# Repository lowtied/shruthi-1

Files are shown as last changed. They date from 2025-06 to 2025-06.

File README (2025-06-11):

Shruthi-1, a digital/analog hybrid MIDI monosynth.

This project is a redesign of the original Shruti-1, with a spec'ed up CPU,
and a focus on easy upgrades/modification of the analog section.
The ATMega644p allows new features in the firmware -- a larger selection of
oscillator algorithms, a bigger selection of wavetables, and a tiny sequencer.

Original developer: Emilie Gillet (emilie.o.gillet@gmail.com)

The firmware is released under a GPL3.0 license. It includes a
reimplementation of the formant synthesis algorithm used in Peter Knight's
Cantarino speech synthesizer.

The PCB layouts and schematics (in /hardware/shruthi/design/pcb)
are released under a Creative Commons cc-by-sa 3.0 license - except for some
discontinued filter boards which were released under a cc-by-nc-sa 3.0 license.

Documentation, analyses, simulations and 3D models are released under a
Creative Commons cc-by-sa 3.0 license.

PCB art:
- "saraswati" by Francois Barbut.
- "peacock_face" by Emilie Gillet.
- "radha" by Emilie Gillet.

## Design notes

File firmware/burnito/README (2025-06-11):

Burnito is a firmware for the Shruthi-1 digital board with a very specific
purpose: burn I2C eeproms with Shruthi-1 presets.

This firmware contains a large 16kb blob in flash with the eeprom contents. At
boot, it tries to recognize the size of the eeprom, and writes the relevant
part of this blob to the eeprom. Afterwards, the data is read back from the
eeprom and compared to the original.

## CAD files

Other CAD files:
hardware/enclosure/shruthi_xt.dwg

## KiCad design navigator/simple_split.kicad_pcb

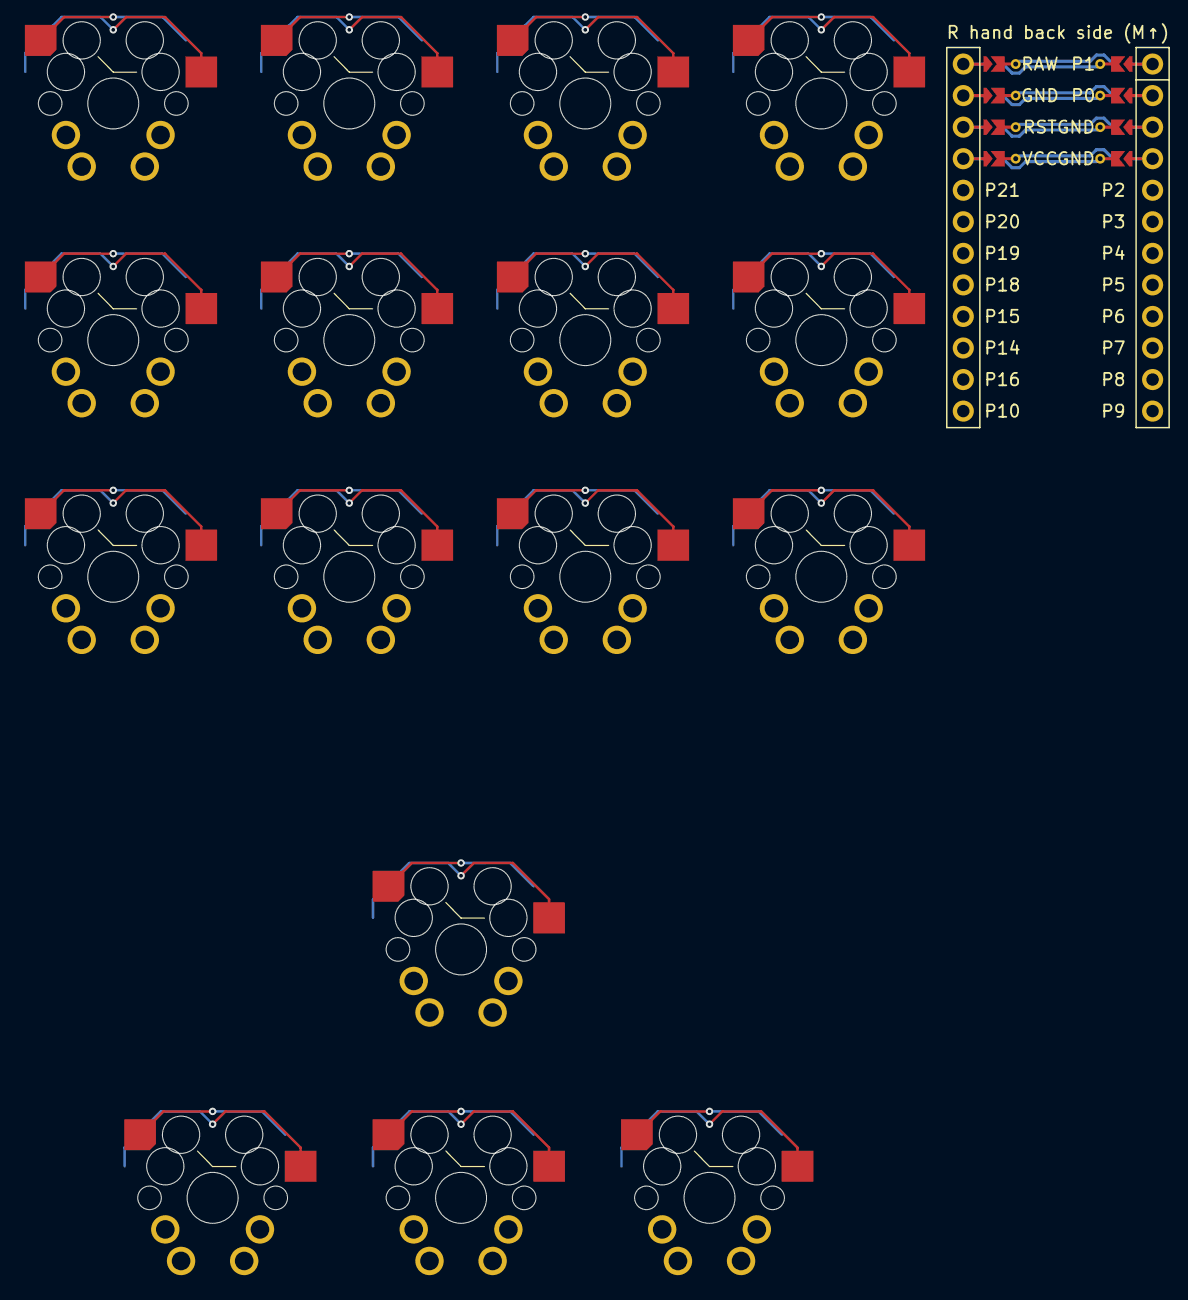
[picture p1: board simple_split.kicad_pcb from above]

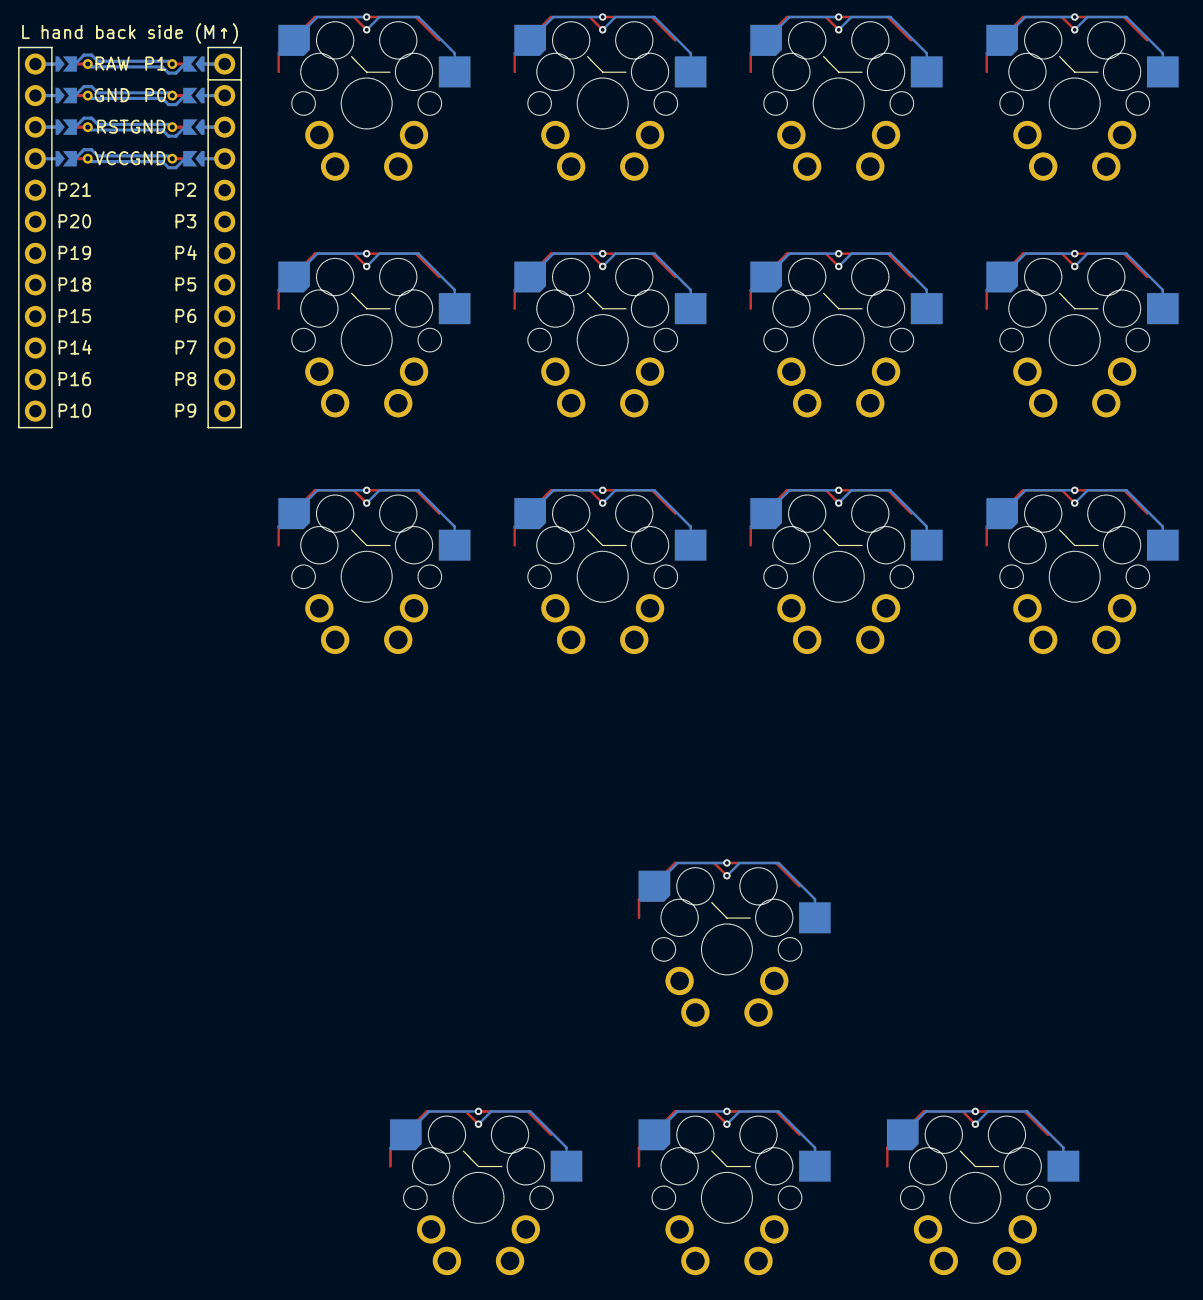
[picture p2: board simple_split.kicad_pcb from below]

Board: 2 copper layers, 17 parts (16 on the bottom side), 13 nets.

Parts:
MCU1: mcu_nice_nano
S1, S2, S3, S4, S5, S6, S7, S8, S9, S10, S11, S12, S13, S14, S15, S16: switch_mx

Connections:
GND: MCU1.103, MCU1.104, MCU1.123, S1.1, S2.1, S3.1, S4.1, S5.1, S6.1, S7.1, S8.1, S9.1, S10.1, S11.1, S12.1, S13.1, S14.1, S15.1, S16.1
matrix_inner_bottom: MCU1.9, S10.2
matrix_inner_home: MCU1.101, S11.2
matrix_inner_top: MCU1.20, S12.2
matrix_middle_bottom: MCU1.7, S7.2
matrix_middle_home: MCU1.14, S8.2
matrix_middle_top: MCU1.18, S9.2
matrix_pinky_bottom: MCU1.5, S1.2
matrix_pinky_home: MCU1.16, S2.2
matrix_pinky_top: MCU1.10, S3.2
matrix_ring_bottom: MCU1.6, S4.2
matrix_ring_home: MCU1.15, S5.2
matrix_ring_top: MCU1.17, S6.2

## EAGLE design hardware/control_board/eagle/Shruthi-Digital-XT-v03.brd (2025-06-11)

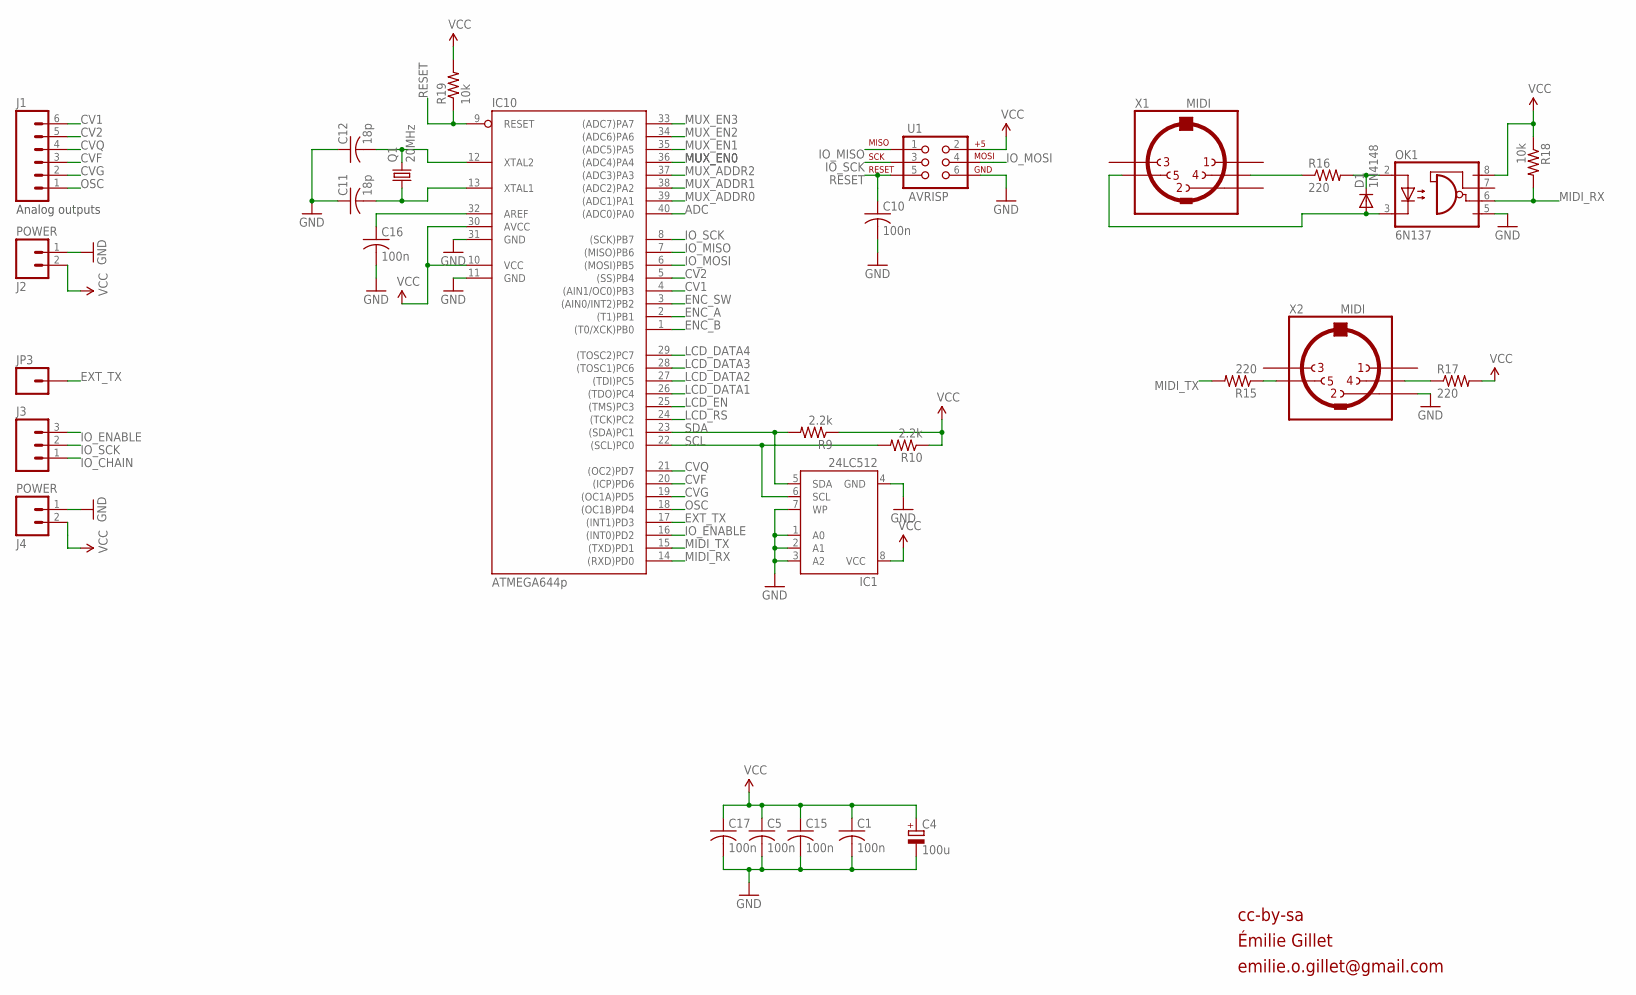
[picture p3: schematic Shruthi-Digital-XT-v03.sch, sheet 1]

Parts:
C1, C5, C10, C15, C16, C17: 100n; C025-024X044
C4: 100u; E2,5-7
C11, C12: 18p; C025-024X044
D1: 1N4148; D-5
IC1: 24LC512; DIL08
IC10: ATMEGA644p; DIL40
J1: M06SIP; 1X06
J2, J4: POWER; 1X02
J3: M03PTH; 1X03
JP3: M01PTH; 1X01
OK1: 6N137; DIL08
Q1: 20MHz; HC49U-V
R9, R10: 2.2k; 0204/7
R15, R16, R17: 220; 0204/7
R18, R19: 10k; 0204/7
U1: AVRISP; 2X3
X1, X2: MIDI; MAB5SH

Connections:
ADC: IC10.40 ((ADC0)PA0); also elsewhere on the board
CV1: IC10.4 ((AIN1/OC0)PB3), J1.6
CV2: IC10.5 ((SS)PB4), J1.5
CVF: IC10.20 ((ICP)PD6), J1.3
CVG: IC10.19 ((OC1A)PD5), J1.2
CVQ: IC10.21 ((OC2)PD7), J1.4
ENC_A: IC10.2 ((T1)PB1); also elsewhere on the board
ENC_B: IC10.1 ((T0/XCK)PB0); also elsewhere on the board
ENC_SW: IC10.3 ((AIN0/INT2)PB2); also elsewhere on the board
EXT_TX: IC10.17 ((INT1)PD3), JP3.1
GND: C1.2, C4.-, C5.2, C10.2, C11.1, C12.1, C15.2, C16.2, C17.2, IC1.1 (A0), IC1.2 (A1), IC1.3 (A2), IC1.4 (GND), IC1.7 (WP), IC10.11 (GND), IC10.31 (GND), J2.1, J4.1, OK1.5 (GND), U1.6, X2.2; also elsewhere on the board
IO_CHAIN: J3.1; also elsewhere on the board
IO_ENABLE: IC10.16 ((INT0)PD2), J3.3; also elsewhere on the board
IO_MISO: IC10.7 ((MISO)PB6), U1.1; also elsewhere on the board
IO_MOSI: IC10.6 ((MOSI)PB5), U1.4; also elsewhere on the board
IO_SCK: IC10.8 ((SCK)PB7), J3.2, U1.3; also elsewhere on the board
LCD_DATA1: IC10.26 ((TDO)PC4); also elsewhere on the board
LCD_DATA2: IC10.27 ((TDI)PC5); also elsewhere on the board
LCD_DATA3: IC10.28 ((TOSC1)PC6); also elsewhere on the board
LCD_DATA4: IC10.29 ((TOSC2)PC7); also elsewhere on the board
LCD_EN: IC10.25 ((TMS)PC3); also elsewhere on the board
LCD_RS: IC10.24 ((TCK)PC2); also elsewhere on the board
MIDI_RX: IC10.14 ((RXD)PD0), OK1.6 (VO), R18.2
MIDI_TX: IC10.15 ((TXD)PD1), R15.2
MUX_ADDR0: IC10.39 ((ADC1)PA1); also elsewhere on the board
MUX_ADDR1: IC10.38 ((ADC2)PA2); also elsewhere on the board
MUX_ADDR2: IC10.37 ((ADC3)PA3); also elsewhere on the board
MUX_EN0: IC10.36 ((ADC4)PA4); also elsewhere on the board
MUX_EN1: IC10.35 ((ADC5)PA5); also elsewhere on the board
MUX_EN2: IC10.34 ((ADC6)PA6); also elsewhere on the board
MUX_EN3: IC10.33 ((ADC7)PA7); also elsewhere on the board
unnamed: R15.1, X2.5
unnamed: C16.1, IC10.32 (AREF)
unnamed: D1.C, OK1.2 (A), R16.2
unnamed: R17.1, X2.4
unnamed: R16.1, X1.4
unnamed: D1.A, OK1.3 (C), X1.5
unnamed: C11.2, IC10.13 (XTAL1), Q1.1
unnamed: C12.2, IC10.12 (XTAL2), Q1.2
OSC: IC10.18 ((OC1B)PD4), J1.1
RESET: C10.1, IC10.9 (RESET), R19.1, U1.5
SCL: IC1.6 (SCL), IC10.22 ((SCL)PC0), R10.2
SDA: IC1.5 (SDA), IC10.23 ((SDA)PC1), R9.2
VCC: C1.1, C4.+, C5.1, C15.1, C17.1, IC1.8 (VCC), IC10.10 (VCC), IC10.30 (AVCC), J2.2, J4.2, OK1.8 (VCC), R9.1, R10.1, R17.2, R18.1, R19.2, U1.2; also elsewhere on the board

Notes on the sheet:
Analog outputs
cc-by-sa
Émilie Gillet
emilie.o.gillet@gmail.com

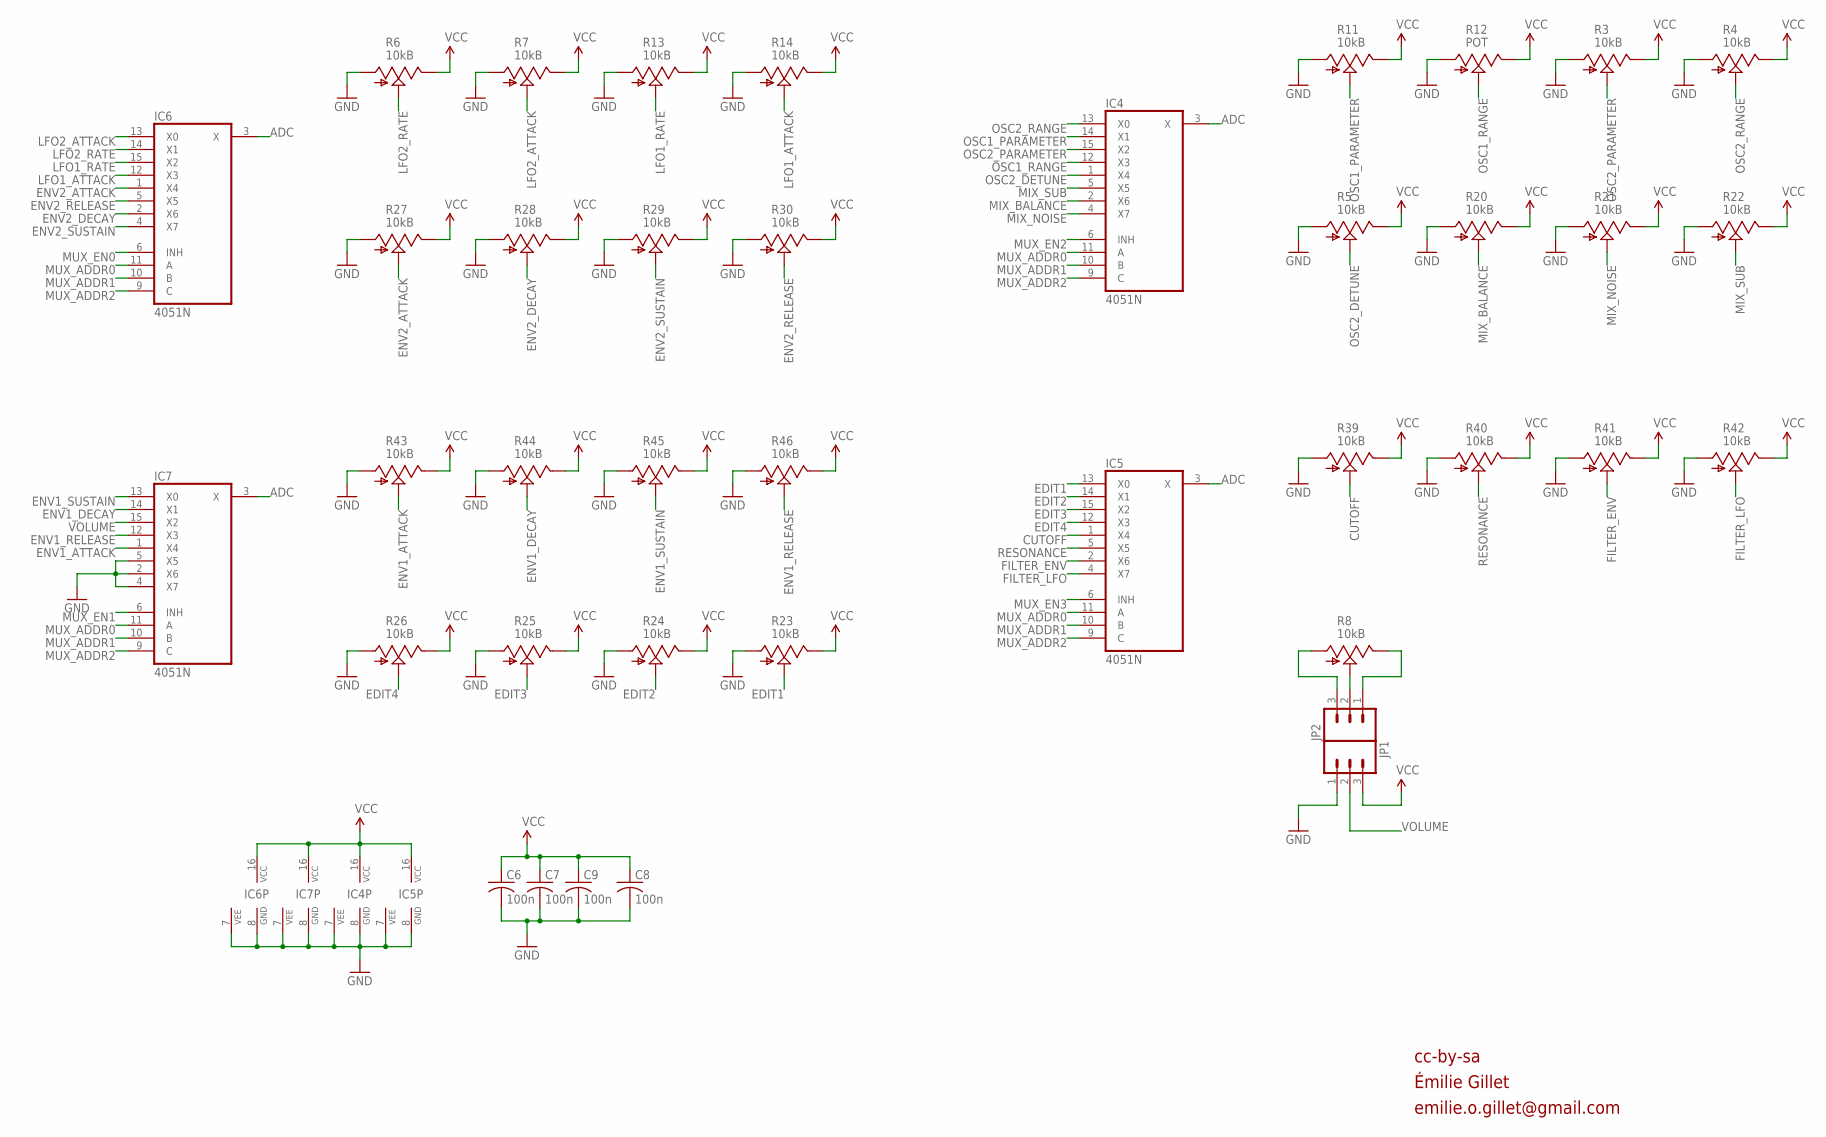
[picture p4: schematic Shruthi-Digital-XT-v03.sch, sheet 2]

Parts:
C6, C7, C8, C9: 100n; C025-024X044
IC4, IC5, IC6, IC7: 4051N; DIL16
JP1, JP2: M03PTH; 1X03
R3, R4, R5, R6, R7, R8, R11, R13, R14, R20, R21, R22, R23, R24, R25, R26, R27, R28, R29, R30, R39, R40, R41, R42, R43, R44, R45, R46: 10kB; ALPS_POT_VERTICAL
R12: POT; ALPS_POT_VERTICAL

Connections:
ADC: IC4.3 (X), IC5.3 (X), IC6.3 (X), IC7.3 (X); also elsewhere on the board
CUTOFF: IC5.1 (X4), R39.P$2 (S)
EDIT1: IC5.13 (X0), R23.P$2 (S)
EDIT2: IC5.14 (X1), R24.P$2 (S)
EDIT3: IC5.15 (X2), R25.P$2 (S)
EDIT4: IC5.12 (X3), R26.P$2 (S)
ENV1_ATTACK: IC7.1 (X4), R43.P$2 (S)
ENV1_DECAY: IC7.14 (X1), R44.P$2 (S)
ENV1_RELEASE: IC7.12 (X3), R46.P$2 (S)
ENV1_SUSTAIN: IC7.13 (X0), R45.P$2 (S)
ENV2_ATTACK: IC6.1 (X4), R27.P$2 (S)
ENV2_DECAY: IC6.2 (X6), R28.P$2 (S)
ENV2_RELEASE: IC6.5 (X5), R30.P$2 (S)
ENV2_SUSTAIN: IC6.4 (X7), R29.P$2 (S)
FILTER_ENV: IC5.2 (X6), R41.P$2 (S)
FILTER_LFO: IC5.4 (X7), R42.P$2 (S)
GND: C6.2, C7.2, C8.2, C9.2, IC4.7 (VEE), IC4.8 (GND), IC5.7 (VEE), IC5.8 (GND), IC6.7 (VEE), IC6.8 (GND), IC7.2 (X6), IC7.4 (X7), IC7.5 (X5), IC7.7 (VEE), IC7.8 (GND), JP1.1, R3.P$3 (A), R4.P$3 (A), R5.P$3 (A), R6.P$3 (A), R7.P$3 (A), R11.P$3 (A), R12.P$3 (A), R13.P$3 (A), R14.P$3 (A), R20.P$3 (A), R21.P$3 (A), R22.P$3 (A), R23.P$3 (A), R24.P$3 (A), R25.P$3 (A), R26.P$3 (A), R27.P$3 (A), R28.P$3 (A), R29.P$3 (A), R30.P$3 (A), R39.P$3 (A), R40.P$3 (A), R41.P$3 (A), R42.P$3 (A), R43.P$3 (A), R44.P$3 (A), R45.P$3 (A), R46.P$3 (A); also elsewhere on the board
LFO1_ATTACK: IC6.12 (X3), R14.P$2 (S)
LFO1_RATE: IC6.15 (X2), R13.P$2 (S)
LFO2_ATTACK: IC6.13 (X0), R7.P$2 (S)
LFO2_RATE: IC6.14 (X1), R6.P$2 (S)
MIX_BALANCE: IC4.2 (X6), R20.P$2 (S)
MIX_NOISE: IC4.4 (X7), R21.P$2 (S)
MIX_SUB: IC4.5 (X5), R22.P$2 (S)
MUX_ADDR0: IC4.11 (A), IC5.11 (A), IC6.11 (A), IC7.11 (A); also elsewhere on the board
MUX_ADDR1: IC4.10 (B), IC5.10 (B), IC6.10 (B), IC7.10 (B); also elsewhere on the board
MUX_ADDR2: IC4.9 (C), IC5.9 (C), IC6.9 (C), IC7.9 (C); also elsewhere on the board
MUX_EN0: IC6.6 (INH); also elsewhere on the board
MUX_EN1: IC7.6 (INH); also elsewhere on the board
MUX_EN2: IC4.6 (INH); also elsewhere on the board
MUX_EN3: IC5.6 (INH); also elsewhere on the board
unnamed: JP2.3, R8.P$3 (A)
unnamed: JP2.1, R8.P$1 (E)
unnamed: JP2.2, R8.P$2 (S)
OSC1_PARAMETER: IC4.14 (X1), R11.P$2 (S)
OSC1_RANGE: IC4.12 (X3), R12.P$2 (S)
OSC2_DETUNE: IC4.1 (X4), R5.P$2 (S)
OSC2_PARAMETER: IC4.15 (X2), R3.P$2 (S)
OSC2_RANGE: IC4.13 (X0), R4.P$2 (S)
RESONANCE: IC5.5 (X5), R40.P$2 (S)
VCC: C6.1, C7.1, C8.1, C9.1, IC4.16 (VCC), IC5.16 (VCC), IC6.16 (VCC), IC7.16 (VCC), JP1.3, R3.P$1 (E), R4.P$1 (E), R5.P$1 (E), R6.P$1 (E), R7.P$1 (E), R11.P$1 (E), R12.P$1 (E), R13.P$1 (E), R14.P$1 (E), R20.P$1 (E), R21.P$1 (E), R22.P$1 (E), R23.P$1 (E), R24.P$1 (E), R25.P$1 (E), R26.P$1 (E), R27.P$1 (E), R28.P$1 (E), R29.P$1 (E), R30.P$1 (E), R39.P$1 (E), R40.P$1 (E), R41.P$1 (E), R42.P$1 (E), R43.P$1 (E), R44.P$1 (E), R45.P$1 (E), R46.P$1 (E); also elsewhere on the board
VOLUME: IC7.15 (X2), JP1.2

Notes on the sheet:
cc-by-sa
Émilie Gillet
emilie.o.gillet@gmail.com

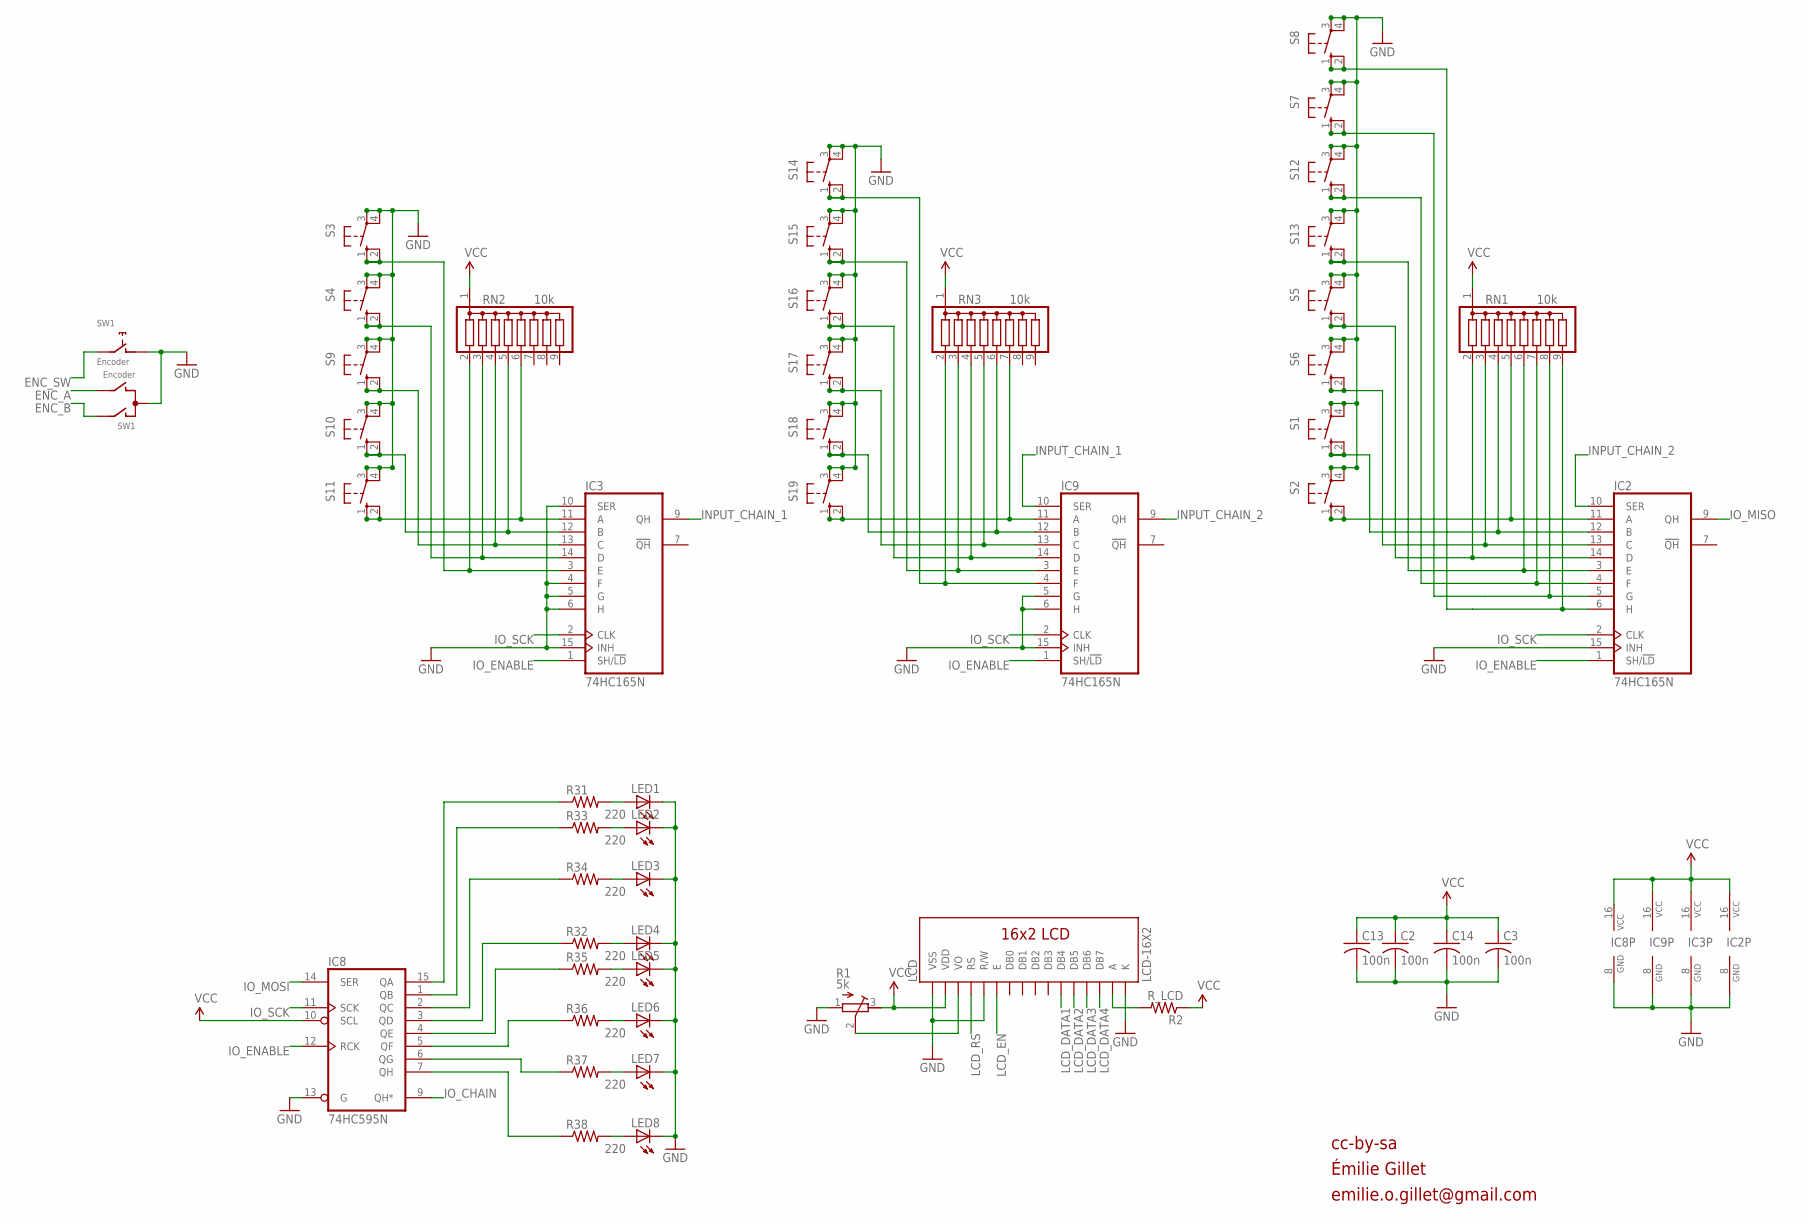
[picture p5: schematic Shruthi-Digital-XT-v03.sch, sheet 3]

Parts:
C2, C3, C13, C14: 100n; C025-024X044
IC2, IC3, IC9: 74HC165N; DIL16
IC8: 74HC595N; DIL16
LCD: LCD-16X2
LED1, LED2, LED3, LED4, LED5, LED6, LED7, LED8: LED3MM
R1: 5k; RTRIM3339P
R2: R_LCD; 0204/7
R31, R32, R33, R34, R35, R36, R37, R38: 220; 0204/7
RN1, RN2, RN3: 10k; SIL9
S1, S2, S3, S4, S5, S6, S7, S8, S9, S10, S11, S12, S13, S14, S15, S16, S17, S18, S19: 40-XX; B3F-40XX
SW1: Encoder; ALPS_EC12E_SW

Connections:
ENC_A: SW1.B; also elsewhere on the board
ENC_B: SW1.A; also elsewhere on the board
ENC_SW: SW1.E (2); also elsewhere on the board
GND: C2.2, C3.2, C13.2, C14.2, IC2.8 (GND), IC2.15 (INH), IC3.4 (F), IC3.5 (G), IC3.6 (H), IC3.8 (GND), IC3.10 (SER), IC3.15 (INH), IC8.8 (GND), IC8.13 (G), IC9.5 (G), IC9.6 (H), IC9.8 (GND), IC9.15 (INH), LCD.1 (VSS), LCD.5 (R/W), LCD.16 (K), LED1.K (C), LED2.K (C), LED3.K (C), LED4.K (C), LED5.K (C), LED6.K (C), LED7.K (C), LED8.K (C), R1.1 (E), S1.3, S1.4 (P1), S2.3, S2.4 (P1), S3.3, S3.4 (P1), S4.3, S4.4 (P1), S5.3, S5.4 (P1), S6.3, S6.4 (P1), S7.3, S7.4 (P1), S8.3, S8.4 (P1), S9.3, S9.4 (P1), S10.3, S10.4 (P1), S11.3, S11.4 (P1), S12.3, S12.4 (P1), S13.3, S13.4 (P1), S14.3, S14.4 (P1), S15.3, S15.4 (P1), S16.3, S16.4 (P1), S17.3, S17.4 (P1), S18.3, S18.4 (P1), S19.3, S19.4 (P1), SW1.C, SW1.D (1); also elsewhere on the board
INPUT_CHAIN_1: IC3.9 (QH), IC9.10 (SER)
INPUT_CHAIN_2: IC2.10 (SER), IC9.9 (QH)
IO_CHAIN: IC8.9 (QH*); also elsewhere on the board
IO_ENABLE: IC2.1 (SH/!LD), IC3.1 (SH/!LD), IC8.12 (RCK), IC9.1 (SH/!LD); also elsewhere on the board
IO_MISO: IC2.9 (QH); also elsewhere on the board
IO_MOSI: IC8.14 (SER); also elsewhere on the board
IO_SCK: IC2.2 (CLK), IC3.2 (CLK), IC8.11 (SCK), IC9.2 (CLK); also elsewhere on the board
LCD_DATA1: LCD.11 (DB4); also elsewhere on the board
LCD_DATA2: LCD.12 (DB5); also elsewhere on the board
LCD_DATA3: LCD.13 (DB6); also elsewhere on the board
LCD_DATA4: LCD.14 (DB7); also elsewhere on the board
LCD_EN: LCD.6 (E); also elsewhere on the board
LCD_RS: LCD.4 (RS); also elsewhere on the board
unnamed: IC8.2 (QC), R34.1
unnamed: IC9.11 (A), RN3.7, S19.1 (S), S19.2 (S1)
unnamed: IC9.3 (E), RN3.3, S15.1 (S), S15.2 (S1)
unnamed: IC2.4 (F), RN1.7, S12.1 (S), S12.2 (S1)
unnamed: IC2.14 (D), RN1.2, S5.1 (S), S5.2 (S1)
unnamed: IC2.13 (C), RN1.3, S6.1 (S), S6.2 (S1)
unnamed: IC2.12 (B), RN1.4, S1.1 (S), S1.2 (S1)
unnamed: IC2.11 (A), RN1.5, S2.1 (S), S2.2 (S1)
unnamed: IC2.3 (E), RN1.6, S13.1 (S), S13.2 (S1)
unnamed: IC2.5 (G), RN1.8, S7.1 (S), S7.2 (S1)
unnamed: IC2.6 (H), RN1.9, S8.1 (S), S8.2 (S1)
unnamed: IC8.15 (QA), R31.1
unnamed: IC8.1 (QB), R33.1
unnamed: IC8.3 (QD), R32.1
unnamed: IC8.4 (QE), R35.1
unnamed: IC8.5 (QF), R36.1
unnamed: IC8.7 (QH), R38.1
unnamed: IC8.6 (QG), R37.1
unnamed: IC3.14 (D), RN2.3, S4.1 (S), S4.2 (S1)
unnamed: IC3.13 (C), RN2.4, S9.1 (S), S9.2 (S1)
unnamed: IC3.12 (B), RN2.5, S10.1 (S), S10.2 (S1)
unnamed: IC3.11 (A), RN2.6, S11.1 (S), S11.2 (S1)
unnamed: LED1.A, R31.2
unnamed: LED2.A, R33.2
unnamed: LED3.A, R34.2
unnamed: LED4.A, R32.2
unnamed: LED5.A, R35.2
unnamed: LED6.A, R36.2
unnamed: LED7.A, R37.2
unnamed: LED8.A, R38.2
unnamed: IC3.3 (E), RN2.2, S3.1 (S), S3.2 (S1)
unnamed: IC9.4 (F), RN3.2, S14.1 (S), S14.2 (S1)
unnamed: IC9.14 (D), RN3.4, S16.1 (S), S16.2 (S1)
unnamed: IC9.13 (C), RN3.5, S17.1 (S), S17.2 (S1)
unnamed: IC9.12 (B), RN3.6, S18.1 (S), S18.2 (S1)
unnamed: LCD.3 (VO), R1.2 (S)
unnamed: LCD.15 (A), R2.2
VCC: C2.1, C3.1, C13.1, C14.1, IC2.16 (VCC), IC3.16 (VCC), IC8.10 (SCL), IC8.16 (VCC), IC9.16 (VCC), LCD.2 (VDD), R1.3 (A), R2.1, RN1.1, RN2.1, RN3.1; also elsewhere on the board

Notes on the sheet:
cc-by-sa
Émilie Gillet
emilie.o.gillet@gmail.com

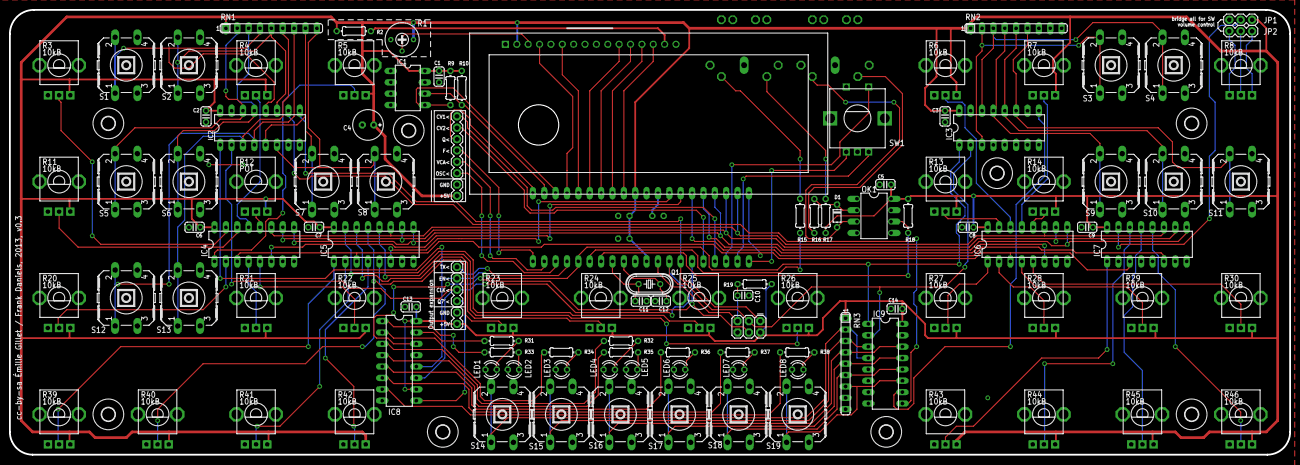
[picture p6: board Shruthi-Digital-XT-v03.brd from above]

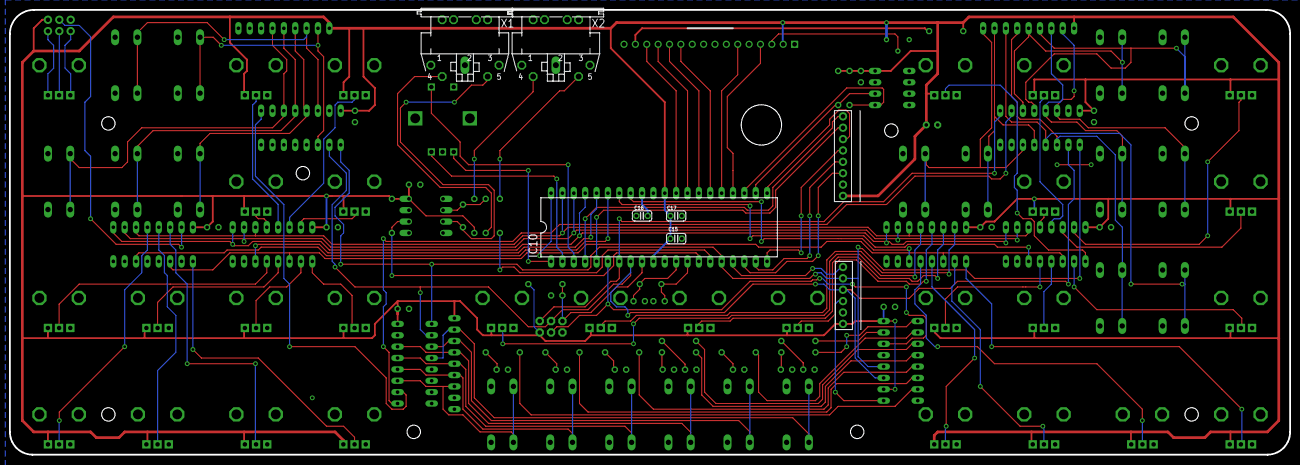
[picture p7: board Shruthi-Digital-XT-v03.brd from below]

Board: 2 copper layers, 286.0 x 99.4 mm, 128 parts (6 on the bottom side), 115 nets.

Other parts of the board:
U$1, U$3, U$4, U$6, U$7, U$8, U$10, U$11: 3,0
U$5: V2_LOGO_SHRUTHI_DIGITAL
U$9: V2_LOGO_DINGBAT1

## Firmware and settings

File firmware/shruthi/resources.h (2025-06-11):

// Copyright 2009 Emilie Gillet.
//
// Author: Emilie Gillet (emilie.o.gillet@gmail.com)
//
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
// -----------------------------------------------------------------------------
//
// Resources definitions.
//
// Automatically generated with:
// make resources


#ifndef SHRUTHI_RESOURCES_H_
#define SHRUTHI_RESOURCES_H_


#include "avrlib/base.h"

#include <avr/pgmspace.h>


#include "avrlib/resources_manager.h"

namespace shruthi {

typedef uint16_t ResourceId;

extern const prog_char* const string_table[];

extern const prog_uint16_t* const lookup_table_table[];

extern const prog_uint32_t* const lookup_table32_table[];

extern const prog_uint8_t* const waveform_table[];

extern const prog_uint8_t* const character_table[];

extern const prog_uint16_t lut_res_lfo_increments[] PROGMEM;
extern const prog_uint16_t lut_res_env_portamento_increments[] PROGMEM;
extern const prog_uint16_t lut_res_oscillator_increments[] PROGMEM;
extern const prog_uint16_t lut_res_fm_frequency_ratios[] PROGMEM;
extern const prog_uint16_t lut_res_scale_just[] PROGMEM;
extern const prog_uint16_t lut_res_scale_pythagorean[] PROGMEM;
extern const prog_uint16_t lut_res_scale_1_4_eb[] PROGMEM;
extern const prog_uint16_t lut_res_scale_1_4_e[] PROGMEM;
extern const prog_uint16_t lut_res_scale_1_4_ea[] PROGMEM;
extern const prog_uint16_t lut_res_scale_bhairav[] PROGMEM;
extern const prog_uint16_t lut_res_scale_gunakri[] PROGMEM;
extern const prog_uint16_t lut_res_scale_marwa[] PROGMEM;
extern const prog_uint16_t lut_res_scale_shree[] PROGMEM;
extern const prog_uint16_t lut_res_scale_purvi[] PROGMEM;
extern const prog_uint16_t lut_res_scale_bilawal[] PROGMEM;
extern const prog_uint16_t lut_res_scale_yaman[] PROGMEM;
extern const prog_uint16_t lut_res_scale_kafi[] PROGMEM;
extern const prog_uint16_t lut_res_scale_bhimpalasree[] PROGMEM;
extern const prog_uint16_t lut_res_scale_darbari[] PROGMEM;
extern const prog_uint16_t lut_res_scale_rageshree[] PROGMEM;
extern const prog_uint16_t lut_res_scale_khamaj[] PROGMEM;
extern const prog_uint16_t lut_res_scale_mimal[] PROGMEM;
extern const prog_uint16_t lut_res_scale_parameshwari[] PROGMEM;
extern const prog_uint16_t lut_res_scale_rangeshwari[] PROGMEM;
extern const prog_uint16_t lut_res_scale_gangeshwari[] PROGMEM;
extern const prog_uint16_t lut_res_scale_kameshwari[] PROGMEM;
extern const prog_uint16_t lut_res_scale_palas_kafi[] PROGMEM;
extern const prog_uint16_t lut_res_scale_natbhairav[] PROGMEM;
extern const prog_uint16_t lut_res_scale_m_kauns[] PROGMEM;
extern const prog_uint16_t lut_res_scale_bairagi[] PROGMEM;
extern const prog_uint16_t lut_res_scale_b_todi[] PROGMEM;
extern const prog_uint16_t lut_res_scale_chandradeep[] PROGMEM;
extern const prog_uint16_t lut_res_scale_kaushik_todi[] PROGMEM;
extern const prog_uint16_t lut_res_scale_jogeshwari[] PROGMEM;
extern const prog_uint16_t lut_res_arpeggiator_patterns[] PROGMEM;
extern const prog_uint16_t lut_res_groove_swing[] PROGMEM;
extern const prog_uint16_t lut_res_groove_shuffle[] PROGMEM;
extern const prog_uint16_t lut_res_groove_push[] PROGMEM;
extern const prog_uint16_t lut_res_groove_lag[] PROGMEM;
extern const prog_uint16_t lut_res_groove_human[] PROGMEM;
extern const prog_uint16_t lut_res_groove_monkey[] PROGMEM;
extern const prog_uint32_t lut_res_tempo_phase_increment[] PROGMEM;
extern const prog_uint8_t wav_res_formant_sine[] PROGMEM;
extern const prog_uint8_t wav_res_formant_square[] PROGMEM;
extern const prog_uint8_t wav_res_sine[] PROGMEM;
extern const prog_uint8_t wav_res_bandlimited_square_0[] PROGMEM;
extern const prog_uint8_t wav_res_bandlimited_square_1[] PROGMEM;
extern const prog_uint8_t wav_res_bandlimited_square_2[] PROGMEM;
extern const prog_uint8_t wav_res_bandlimited_square_3[] PROGMEM;
extern const prog_uint8_t wav_res_bandlimited_square_4[] PROGMEM;
extern const prog_uint8_t wav_res_bandlimited_square_5[] PROGMEM;
extern const prog_uint8_t wav_res_bandlimited_saw_0[] PROGMEM;
extern const prog_uint8_t wav_res_bandlimited_saw_1[] PROGMEM;
extern const prog_uint8_t wav_res_bandlimited_saw_2[] PROGMEM;
extern const prog_uint8_t wav_res_bandlimited_saw_3[] PROGMEM;
extern const prog_uint8_t wav_res_bandlimited_saw_4[] PROGMEM;
extern const prog_uint8_t wav_res_bandlimited_saw_5[] PROGMEM;
extern const prog_uint8_t wav_res_bandlimited_triangle_0[] PROGMEM;
extern const prog_uint8_t wav_res_bandlimited_triangle_3[] PROGMEM;
extern const prog_uint8_t wav_res_bandlimited_triangle_4[] PROGMEM;
extern const prog_uint8_t wav_res_bandlimited_triangle_5[] PROGMEM;
extern const prog_uint8_t wav_res_vowel_data[] PROGMEM;
extern const prog_uint8_t wav_res_distortion[] PROGMEM;
extern const prog_uint8_t wav_res_env_expo[] PROGMEM;
extern const prog_uint8_t wav_res_ssm2164_linearization[] PROGMEM;
extern const prog_uint8_t wav_res_waves[] PROGMEM;
extern const prog_uint8_t wav_res_wavetables[] PROGMEM;
extern const prog_uint8_t wav_res_version[] PROGMEM;
extern const prog_uint8_t chr_res_special_characters[] PROGMEM;
#define STR_RES_SHAPE 0  // shape
#define STR_RES_PARAMETER 1  // parameter
#define STR_RES_RESONANCE 2  // resonance
#define STR_RES_PRM 3  // prm
#define STR_RES_RANGE 4  // range
#define STR_RES_RNG 5  // rng
#define STR_RES_OP_ 6  // op.
#define STR_RES_OPERATOR 7  // operator
#define STR_RES_DETUNE 8  // detune
#define STR_RES_OSC_MIX 9  // osc mix
#define STR_RES_SUB_OSC_ 10  // sub osc.
#define STR_RES_ENV1TVCF 11  // env1~vcf
#define STR_RES_LFO2TVCF 12  // lfo2~vcf
#define STR_RES_ATTACK 13  // attack
#define STR_RES_ATK 14  // atk
#define STR_RES_DECAY 15  // decay
#define STR_RES_SUSTAIN 16  // sustain
#define STR_RES_RELEASE 17  // release
#define STR_RES_RATE 18  // rate
#define STR_RES_MODULATION 19  // modulation
#define STR_RES_OPERATORS 20  // operators
#define STR_RES_MOD_ 21  // mod.
#define STR_RES_SOURCE 22  // source
#define STR_RES_SRC 23  // src
#define STR_RES_DEST_ 24  // dest.
#define STR_RES_DST 25  // dst
#define STR_RES_AMOUNT 26  // amount
#define STR_RES_AMT 27  // amt
#define STR_RES_MODE 28  // mode
#define STR_RES_OVERDRIVE 29  // overdrive
#define STR_RES__FM 30  // fm
#define STR_RES_FLAVOUR 31  // flavour
#define STR_RES_TIME 32  // time
#define STR_RES_LEVEL 33  // level
#define STR_RES_FDB 34  // fdb
#define STR_RES_FEEDBACK 35  // feedback
#define STR_RES_EQ_ 36  // eq.
#define STR_RES_FDBCK_EQ_ 37  // fdbck eq.
#define STR_RES_TEMPO 38  // tempo
#define STR_RES_BPM 39  // bpm
#define STR_RES_GROOVE 40  // groove
#define STR_RES_DIRECTION 41  // direction
#define STR_RES_PATTERN 42  // pattern
#define STR_RES_DIVISION 43  // division
#define STR_RES_START 44  // start
#define STR_RES_LENGTH 45  // length
#define STR_RES_OCTAVE 46  // octave
#define STR_RES_RAGA 47  // raga
#define STR_RES_PORTA 48  // porta
#define STR_RES_PRT 49  // prt
#define STR_RES_LEGATO 50  // legato
#define STR_RES_TUNING 51  // tuning
#define STR_RES_MIDI_CHAN 52  // midi chan
#define STR_RES_CHN 53  // chn
#define STR_RES_MIDI_OUT 54  // midi out
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

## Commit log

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2025-06-11 move boards into seperate folders, remove uneeded boards
    [Shruthi-Analog-LP2Delay-v02.brd, Shruthi-Analog-LP2Delay-v02.sch, Shruthi-Analog-PoleMixing-v02.brd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]
2025-06-11 move enclosure design files to enclosure directory
    [shruthi_xt.dwg]
2025-06-11 move documentation files into docs folder
    [expo_converter.sch, linear_current_source.sch, shruthi-1_fancy_case.skp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]
2025-06-11 remove v02 svf filter board due to errors in eagle project
    [Shruthi-Analog-SVF-v02.brd, Shruthi-Analog-SVF-v02.sch]
2025-06-11 update all eagle projects to latest versions
    [Shruthi-Analog-LP2Delay-v02.brd, Shruthi-Analog-LP2Delay-v02.sch, Shruthi-Analog-PoleMixing-v02.brd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]
2025-06-11 import eagle project into kicad
    [Shruthi-Digital-XT-v03.brd, Shruthi-Digital-XT-v03.sch, shruthi_control_board_xt_v03.kicad_sch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]
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2025-06-17 remove extra worksheet frame
    [shruthi_control_board_xt_v03_1.kicad_sch, shruthi_control_board_xt_v03_2.kicad_sch, shruthi_control_board_xt_v03_3.kicad_sch]
2025-06-17 update capacitors to use kicad symbols
    [shruthi_control_board_xt_v03_1.kicad_sch, shruthi_control_board_xt_v03_2.kicad_sch, shruthi_control_board_xt_v03_3.kicad_sch]
2025-06-17 update jumpers to use kicad symbols
    [shruthi_control_board_xt_v03_1.kicad_sch]
2025-06-19 update crystal to use kicad symbols
    [shruthi_control_board_xt_v03_1.kicad_sch]
2025-06-19 update vcc to use kicad symbols
    [shruthi_control_board_xt_v03_1.kicad_sch, shruthi_control_board_xt_v03_2.kicad_sch, shruthi_control_board_xt_v03_3.kicad_sch]
2025-06-19 update gnd to use kicad symbols
    [shruthi_control_board_xt_v03_1.kicad_sch, shruthi_control_board_xt_v03_2.kicad_sch, shruthi_control_board_xt_v03_3.kicad_sch]
2025-06-19 update resistors to use kicad symbols
    [shruthi_control_board_xt_v03_1.kicad_sch, shruthi_control_board_xt_v03_3.kicad_sch]
2025-06-19 update atmega644p to use kicad symbols
    [shruthi_control_board_xt_v03_1.kicad_sch]
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2025-06-20 move enclosure files to cad directory
    [shruthi_xt.dwg]
2025-06-20 update 24LC512 to use kicad symbols
    [shruthi_control_board_xt_v03_1.kicad_sch]
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2025-06-20 update AVR ISP to use kicad symbols
    [shruthi_control_board_xt_v03_1.kicad_sch]
2025-06-20 update MIDI circuitry to use kicad symbols
    [shruthi_control_board_xt_v03_1.kicad_sch]
2025-06-20 move bypass capacitors next to respective devices
    [shruthi_control_board_xt_v03_1.kicad_sch]
2025-06-23 fix footprint library location
2025-06-23 update footprints for atmega and 6N137
    [shruthi_control_board_xt_v03.kicad_pcb, shruthi_control_board_xt_v03_1.kicad_sch]
2025-06-23 update 4051 to use kicad symbols
    [shruthi_control_board_xt_v03_2.kicad_sch]
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2025-06-23 update pots to use kicad symbols
    [shruthi_control_board_xt_v03_2.kicad_sch]
2025-06-23 remove aligment lines from User.4 layer
    [shruthi_control_board_xt_v03.kicad_pcb]
2025-06-23 fix pin numbering for pot footprint
    [shruthi_control_board_xt_v03.kicad_pcb]
2025-06-23 update volume jumpers to use kicad symbols
    [shruthi_control_board_xt_v03.kicad_pcb, shruthi_control_board_xt_v03_2.kicad_sch]
2025-06-23 update 75HC165s to use kicad symbols
    [shruthi_control_board_xt_v03_3.kicad_sch]
2025-06-23 update resistor networks to use kicad symbols
    [shruthi_control_board_xt_v03_3.kicad_sch]
2025-06-23 fix extra connections on IC2
    [shruthi_control_board_xt_v03_3.kicad_sch]
2025-06-23 update switches to use kicad symbols
    [shruthi_control_board_xt_v03_3.kicad_sch]
2025-06-23 update footprints on pcb and fix a few minor errors
    [shruthi_control_board_xt_v03.kicad_pcb]
2025-06-23 remove top fill zone and replace bottom fill zone
    [shruthi_control_board_xt_v03.kicad_pcb]
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2025-06-23 update 74HC595 and LED symbols
    [shruthi_control_board_xt_v03_3.kicad_sch]
2025-06-23 remove loose wires and text
    [shruthi_control_board_xt_v03_3.kicad_sch]
2025-06-23 update LCD parts to use kicad symbols
    [shruthi_control_board_xt_v03_3.kicad_sch]
2025-06-23 use original LCD footprint for now
    [shruthi_control_board_xt_v03_3.kicad_sch]
2025-06-24 use 1x8 header instead of separate ones for J1 and J2
    [shruthi_control_board_xt_v03.kicad_pcb, shruthi_control_board_xt_v03_1.kicad_sch]
2025-06-24 update position of board to board connectors
    [shruthi_control_board_xt_v03.kicad_pcb, shruthi_control_board_xt_v03_1.kicad_sch]
2025-06-24 update LED and LED resistor footprints
    [shruthi_control_board_xt_v03.kicad_pcb, shruthi_control_board_xt_v03_3.kicad_sch]
2025-06-24 update footprint for 74HC595
    [shruthi_control_board_xt_v03.kicad_pcb, shruthi_control_board_xt_v03_3.kicad_sch]
2025-06-24 update silkscreen for 74HC165s
    [shruthi_control_board_xt_v03.kicad_pcb, shruthi_control_board_xt_v03_3.kicad_sch]
2025-06-24 update silkscreen for 4051s
    [shruthi_control_board_xt_v03.kicad_pcb]
2025-06-24 update footprint and silkscreen for volume jumpers
    [shruthi_control_board_xt_v03.kicad_pcb, shruthi_control_board_xt_v03_2.kicad_sch]
2025-06-24 update footprint and silkscreen for isp header
    [shruthi_control_board_xt_v03.kicad_pcb, shruthi_control_board_xt_v03_1.kicad_sch]
2025-06-24 update footprints and silkscreen for optocoupler circuitry
    [shruthi_control_board_xt_v03.kicad_pcb, shruthi_control_board_xt_v03_1.kicad_sch]
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2025-06-30 consolidate files related to shruthi-xt into flatter structure
    [Shruthi-Digital-XT-v03.brd, Shruthi-Digital-XT-v03.sch, shruthi_control_board_xt_v03.kicad_pcb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]
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2025-07-01 move all logic components to daughterboard, move MIDI to new board
    [buttons.kicad_sch, control_board.kicad_sch, led_driver.kicad_sch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]

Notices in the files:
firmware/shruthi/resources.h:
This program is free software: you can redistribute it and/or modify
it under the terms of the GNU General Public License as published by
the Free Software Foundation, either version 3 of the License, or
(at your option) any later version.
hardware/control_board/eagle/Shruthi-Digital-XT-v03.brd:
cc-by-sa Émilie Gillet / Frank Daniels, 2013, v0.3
